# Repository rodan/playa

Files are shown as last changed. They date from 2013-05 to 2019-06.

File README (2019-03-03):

 This project has the following feature set:

   - a smallish and spartan music player that can work for weeks between charges
   - a 2Ah Li-poly cell and an integrated charger - 5V input
   - decoding of ogg vorbis, mp3 files
   - microSD (SDHC) is the storage medium. so fat32 and cards bigger than 4G.

  there are 2 components in this repository:
  avr        - contains the C source code for an Atmel-based microcontroller
  beaglebone - contains the C source code for beagle-bone (ARMv7)-based tools
  hardware   - open source hardware for the main board
				the schematic is based on VLSI's Simple DSP Evaluation Board [1]

  Library dependencies for the avr code:

   if using the master branch:
      none (this is a fully standalone version)

   if using the old 'arduino' branch:
      sdfatlib    http://code.google.com/p/sdfatlib/
      vs1063      https://github.com/rodan/vs1063
      IRremote    https://github.com/shirriff/Arduino-IRremote

  Usage:
   - an RC5 remote control provides the control (a Vishay TSOP IR receiver's output goes to PD2).
   - by default music files are played randomly. the following buttons are configured:
   
    VOL-        decrease volume
    VOL+        increase volume
    SUBTITLES   switch between 4 levels of spatial processing (for headphones)
    REWIND      switch to album mode
    CHANNEL-    switch to artist mode
    CHANNEL+    next track in either of the modes
    STOP        sends the player in low power shutdown mode. 
                you need to start it again to exit this.
    NUMBERS 0-9 select artist (which directory from the root of the filesystem to play)
    AV          disable artist selection

  Power consumption profile:
   - jumper/switch open - battery connected only to the charging circuit - < 3uA
   - normal file decoding - 30-40 mA
   - shutdown (after STOP ir command), IR sensor active - 800uA
   - after uC woken up by ir sensor trigger, waiting for a POWER ir sequence (for max 2 seconds) - 4.5mA (this mode has been disabled in the code)
   - if the stereo jack is unused or if the battery level goes below safe LiPo levels then the player enters shutdown mode.

  Known problems and limitations:
   - you should format the SDcard as Fat32 with largest available cluster size
   - no special chars must be used in the filesystem entries, only ascii alphanumeric chars
   - there is a hardcoded MAX_PATH that only allows about 4 parent dirs to any music file

  Tested with:
   - 16G Class 10 Adata card, with ogg files over the 4G barrier

  Author:            Petre Rodan <2b4eda@subdimension.ro>
  Available from:    https://github.com/rodan/playa
  Product pictures:  https://photos.app.goo.gl/nUQuD7HJvfVBpMeQ9
  License:           GNU GPLv3

[1]  http://www.vlsi.fi/en/support/evaluationboards/vs1053vs8053simpledspboard.html

 GNU GPLv3 license:
  
  This program is free software: you can redistribute it and/or modify
  it under the terms of the GNU General Public License as published by
  the Free Software Foundation, either version 3 of the License, or
  (at your option) any later version.
   
  This program is distributed in the hope that it will be useful,
  but WITHOUT ANY WARRANTY; without even the implied warranty of
  MERCHANTABILITY or FITNESS FOR A PARTICULAR PURPOSE.  See the
  GNU General Public License for more details.
   
  You should have received a copy of the GNU General Public License
  along with this program.  If not, see <http://www.gnu.org/licenses/>.

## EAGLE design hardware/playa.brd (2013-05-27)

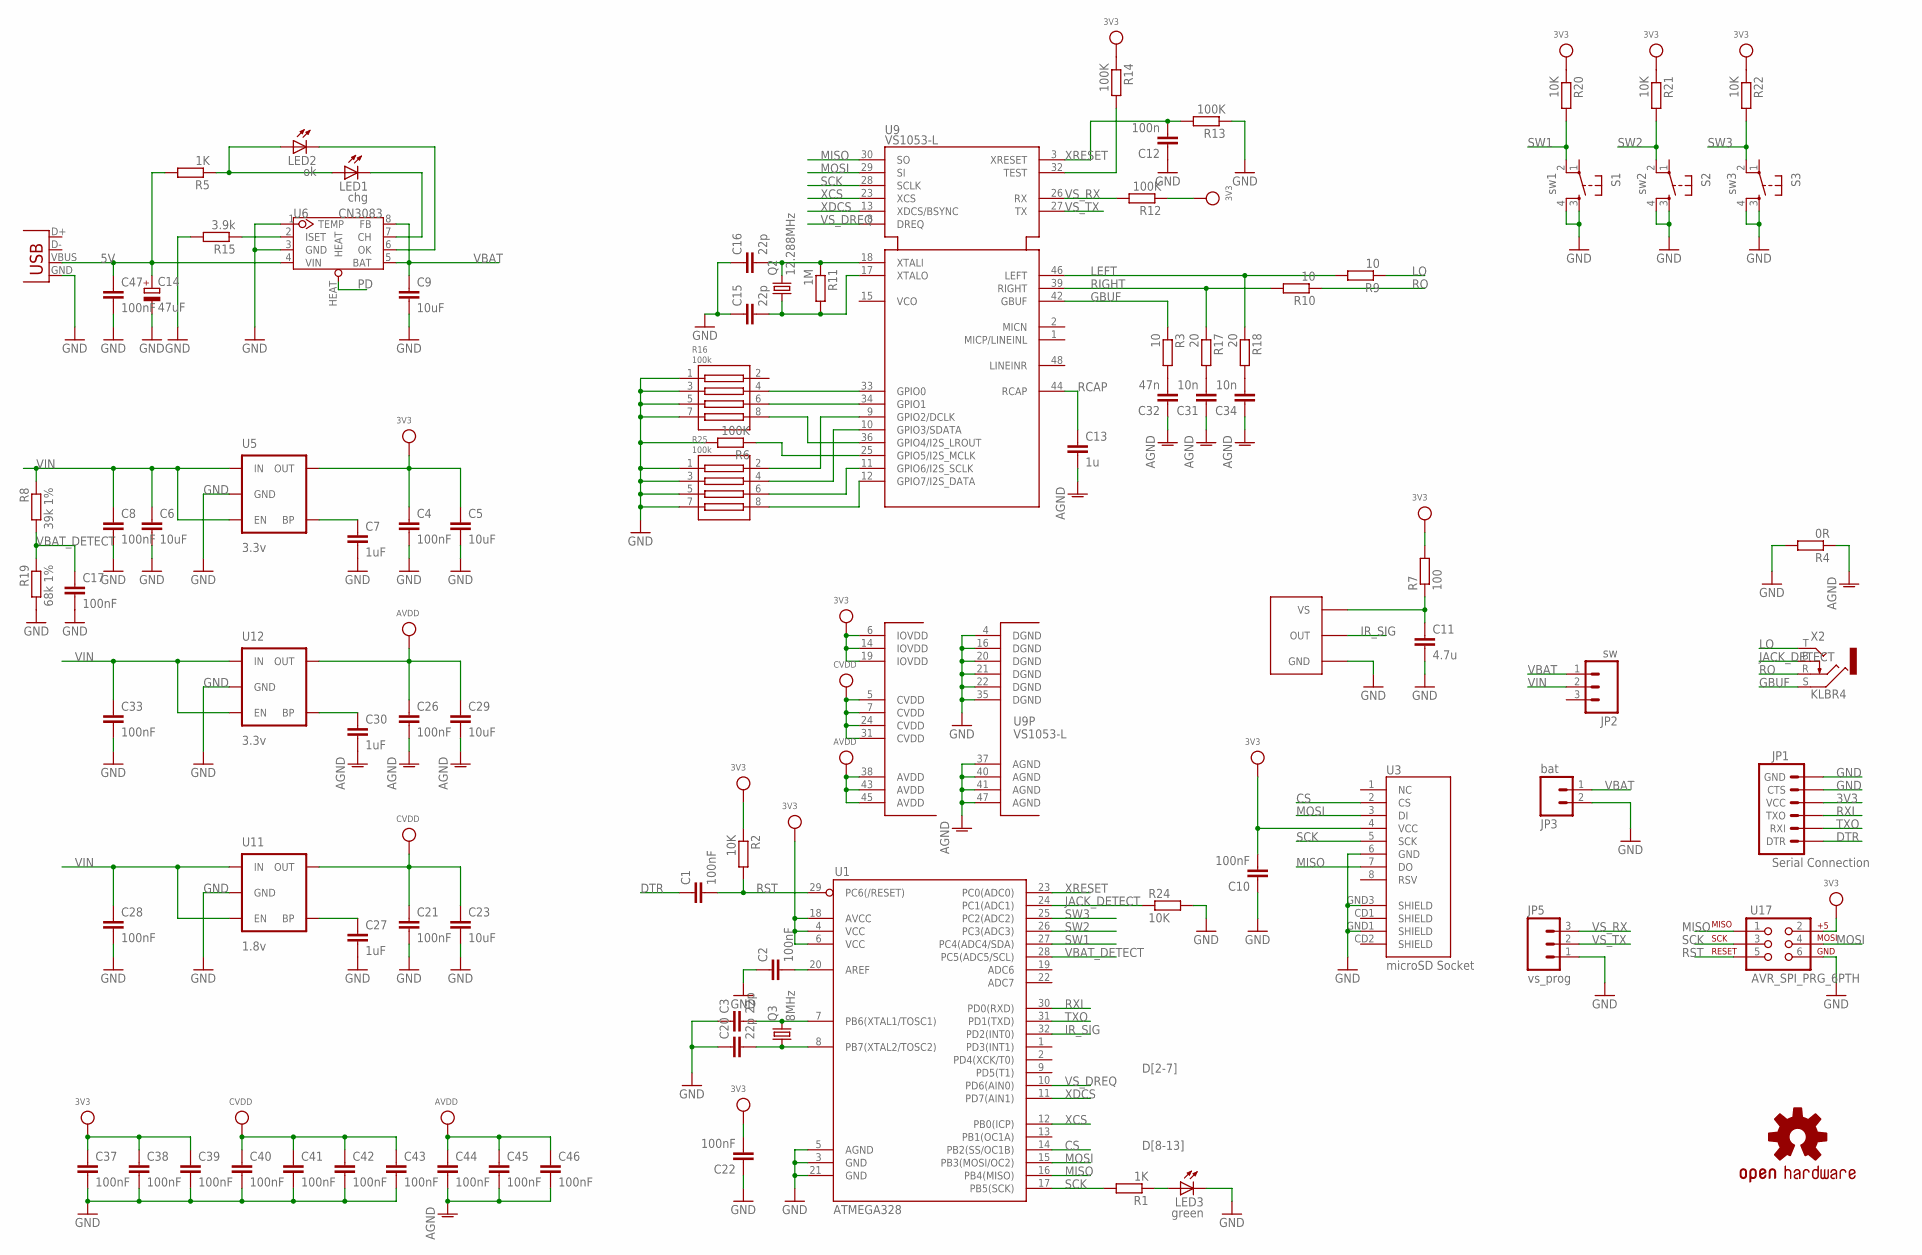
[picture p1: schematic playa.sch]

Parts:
C1, C2, C4, C8, C10, C17, C21, C22, C26, C28, C33, C37, C38, C39, C40, C41, C42, C43, C44, C45, C46, C47: 100nF; C0805
C3, C15, C16, C20: 22p; C0805
C5, C6, C9, C23, C29: 10uF; C1206
C7, C27, C30: 1uF; C0805
C11: 4.7u; C1206
C12: 100n; C0805
C13: 1u; C0805
C14: 47uF; CT7343
C31, C34: 10n; C0805
C32: 47n; C0805
JP1: Serial Connection; 1X06
JP2: sw; 1X03
JP3: bat; 1X02
JP5: vs_prog; 1X03
LED1: chg; CHIP-LED0805
LED2: ok; CHIP-LED0805
LED3: green; CHIP-LED0805
Q2: 12.288MHz; CRYSTAL_5X3.2
Q3: 8MHz; CRYSTAL_5X3.2
R1, R5: 1K; R0805W
R2, R20, R21, R22, R24: 10K; R0805W
R3, R9, R10: 10; R0805W
R4: 0R; R0805W
R6, R12, R13, R14: 100K; R0805W
R7: 100; R0805W
R8: 39k 1%; R0805W
R11: 1M; R0805W
R15: 3.9k; R0805W
R16, R25: 100k; RAS_ARR_1206
R17, R18: 20; R0805W
R19: 68k 1%; R0805W
S1: sw1; TACTILE_SWITCH_SMD
S2: sw2; TACTILE_SWITCH_SMD
S3: sw3; TACTILE_SWITCH_SMD
U1: ATMEGA328; TQFP32-08
U3: microSD Socket; MICRO-SD-SOCKET-PP
U5, U12: 3.3v; SOT23-5
U6: CN3083; SOP8-W/-HEAT
U9: VS1053-L; LQFP48
U11: 1.8v; SOT23-5
U17: AVR_SPI_PRG_6PTH; 2X3
U$3: TSOP312X
U$5: OSHW-LOGOM; OSHW-LOGO-M
X1: USBSMD; USB-MINIB
X2: KLBR4

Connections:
3V3: C4.1, C5.1, C10.2, C22.2, C37.1, C38.1, C39.1, JP1.4 (VCC), R2.1, R7.2, R12.1, R14.1, R20.1, R21.1, R22.1, U1.4 (VCC), U1.6 (VCC), U1.18 (AVCC), U3.4 (VCC), U5.5 (OUT), U9.6 (IOVDD), U9.14 (IOVDD), U9.19 (IOVDD), U17.2
5V: C14.+, C47.1, R5.2, U6.4 (VIN), X1.VBUS
AGND: C13.2, C26.2, C29.2, C30.2, C31.1, C32.1, C34.1, C44.2, C45.2, C46.2, R4.1, U9.37 (AGND), U9.40 (AGND), U9.41 (AGND), U9.47 (AGND)
AVDD: C26.1, C29.1, C44.1, C45.1, C46.1, U9.38 (AVDD), U9.43 (AVDD), U9.45 (AVDD), U12.5 (OUT)
CS: U1.14 (PB2(SS/OC1B)), U3.2 (CS)
CVDD: C21.1, C23.1, C40.1, C41.1, C42.1, C43.1, U9.5 (CVDD), U9.7 (CVDD), U9.24 (CVDD), U9.31 (CVDD), U11.5 (OUT)
DTR: C1.1, JP1.1 (DTR)
GBUF: R3.1, U9.42 (GBUF), X2.S
GND: C2.1, C3.1, C4.2, C5.2, C6.2, C7.2, C8.2, C9.2, C10.1, C11.2, C12.1, C14.-, C15.1, C16.1, C17.2, C20.1, C21.2, C22.1, C23.2, C27.2, C28.2, C33.2, C37.2, C38.2, C39.2, C40.2, C41.2, C42.2, C43.2, C47.2, JP1.5 (CTS), JP1.6 (GND), JP3.2, JP5.1, LED3.C, R4.2, R6.2, R13.1, R15.2, R16.1, R16.3, R16.5, R16.7, R19.2, R24.2, R25.1, R25.3, R25.5, R25.7, S1.3, S1.4, S2.3, S2.4, S3.3, S3.4, U1.3 (GND), U1.5 (AGND), U1.21 (GND), U3.6 (GND), U3.GND1 (SHIELD), U3.GND3 (SHIELD), U5.2 (GND), U6.1 (TEMP), U6.3 (GND), U9.4 (DGND), U9.16 (DGND), U9.20 (DGND), U9.21 (DGND), U9.22 (DGND), U9.35 (DGND), U11.2 (GND), U12.2 (GND), U17.6, U$3.1 (GND), X1.GND
IR_SIG: U1.32 (PD2(INT0)), U$3.3 (OUT)
JACK_DETECT: R24.1, U1.24 (PC1(ADC1)), X2.B
LEFT: R9.2, R18.1, U9.46 (LEFT)
LO: R9.1, X2.T
MISO: U1.16 (PB4(MISO)), U3.7 (DO), U9.30 (SO), U17.1
MOSI: U1.15 (PB3(MOSI/OC2)), U3.3 (DI), U9.29 (SI), U17.4
unnamed: C20.2, Q3.P$1 (1), U1.8 (PB7(XTAL2/TOSC2))
unnamed: C3.2, Q3.P$2 (2), U1.7 (PB6(XTAL1/TOSC1))
unnamed: C2.2, U1.20 (AREF)
unnamed: R16.4, U9.33 (GPIO0)
unnamed: C7.1, U5.4 (BP)
unnamed: R25.8, U9.12 (GPIO7/I2S_DATA)
unnamed: C27.1, U11.4 (BP)
unnamed: C32.2, R3.2
unnamed: R15.1, U6.2 (ISET)
unnamed: C31.2, R17.2
unnamed: C34.2, R18.2
unnamed: R16.6, U9.34 (GPIO1)
unnamed: LED3.A, R1.1
unnamed: LED1.A, LED2.A, R5.1
unnamed: LED1.C, U6.7 (CH)
unnamed: LED2.C, U6.6 (OK)
unnamed: R16.8, U9.36 (GPIO4/I2S_LROUT)
unnamed: C30.1, U12.4 (BP)
unnamed: R6.1, U9.25 (GPIO5/I2S_MCLK)
unnamed: R25.2, U9.9 (GPIO2/DCLK)
unnamed: R25.4, U9.10 (GPIO3/SDATA)
unnamed: R25.6, U9.11 (GPIO6/I2S_SCLK)
unnamed: C11.1, R7.1, U$3.2 (VS)
unnamed: R14.2, U9.32 (TEST)
PD: U6.HEAT
RCAP: C13.1, U9.44 (RCAP)
RIGHT: R10.2, R17.1, U9.39 (RIGHT)
RO: R10.1, X2.R
RST: C1.2, R2.2, U1.29 (PC6(/RESET)), U17.5
RXI: JP1.3 (TXO), U1.30 (PD0(RXD))
SCK: R1.2, U1.17 (PB5(SCK)), U3.5 (SCK), U9.28 (SCLK), U17.3
SW1: R20.2, S1.2, U1.27 (PC4(ADC4/SDA))
SW2: R21.2, S2.2, U1.26 (PC3(ADC3))
SW3: R22.2, S3.2, U1.25 (PC2(ADC2))
TXO: JP1.2 (RXI), U1.31 (PD1(TXD))
VBAT: C9.1, JP2.1, JP3.1, U6.5 (BAT), U6.8 (FB)
VBAT_DETECT: C17.1, R8.2, R19.1, U1.28 (PC5(ADC5/SCL))
VIN: C6.1, C8.1, C28.1, C33.1, JP2.2, R8.1, U5.1 (IN), U5.3 (EN), U11.1 (IN), U11.3 (EN), U12.1 (IN), U12.3 (EN)
VS_DREQ: U1.10 (PD6(AIN0)), U9.8 (DREQ)
VS_RX: JP5.3, R12.2, U9.26 (RX)
VS_TX: JP5.2, U9.27 (TX)
VS_XTALI: C16.2, Q2.P$2 (2), R11.1, U9.18 (XTALI)
VS_XTALO: C15.2, Q2.P$1 (1), R11.2, U9.17 (XTALO)
XCS: U1.12 (PB0(ICP)), U9.23 (XCS)
XDCS: U1.11 (PD7(AIN1)), U9.13 (XDCS/BSYNC)
XRESET: C12.2, R13.2, U1.23 (PC0(ADC0)), U9.3 (XRESET)

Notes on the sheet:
D[2-7]
D[8-13]

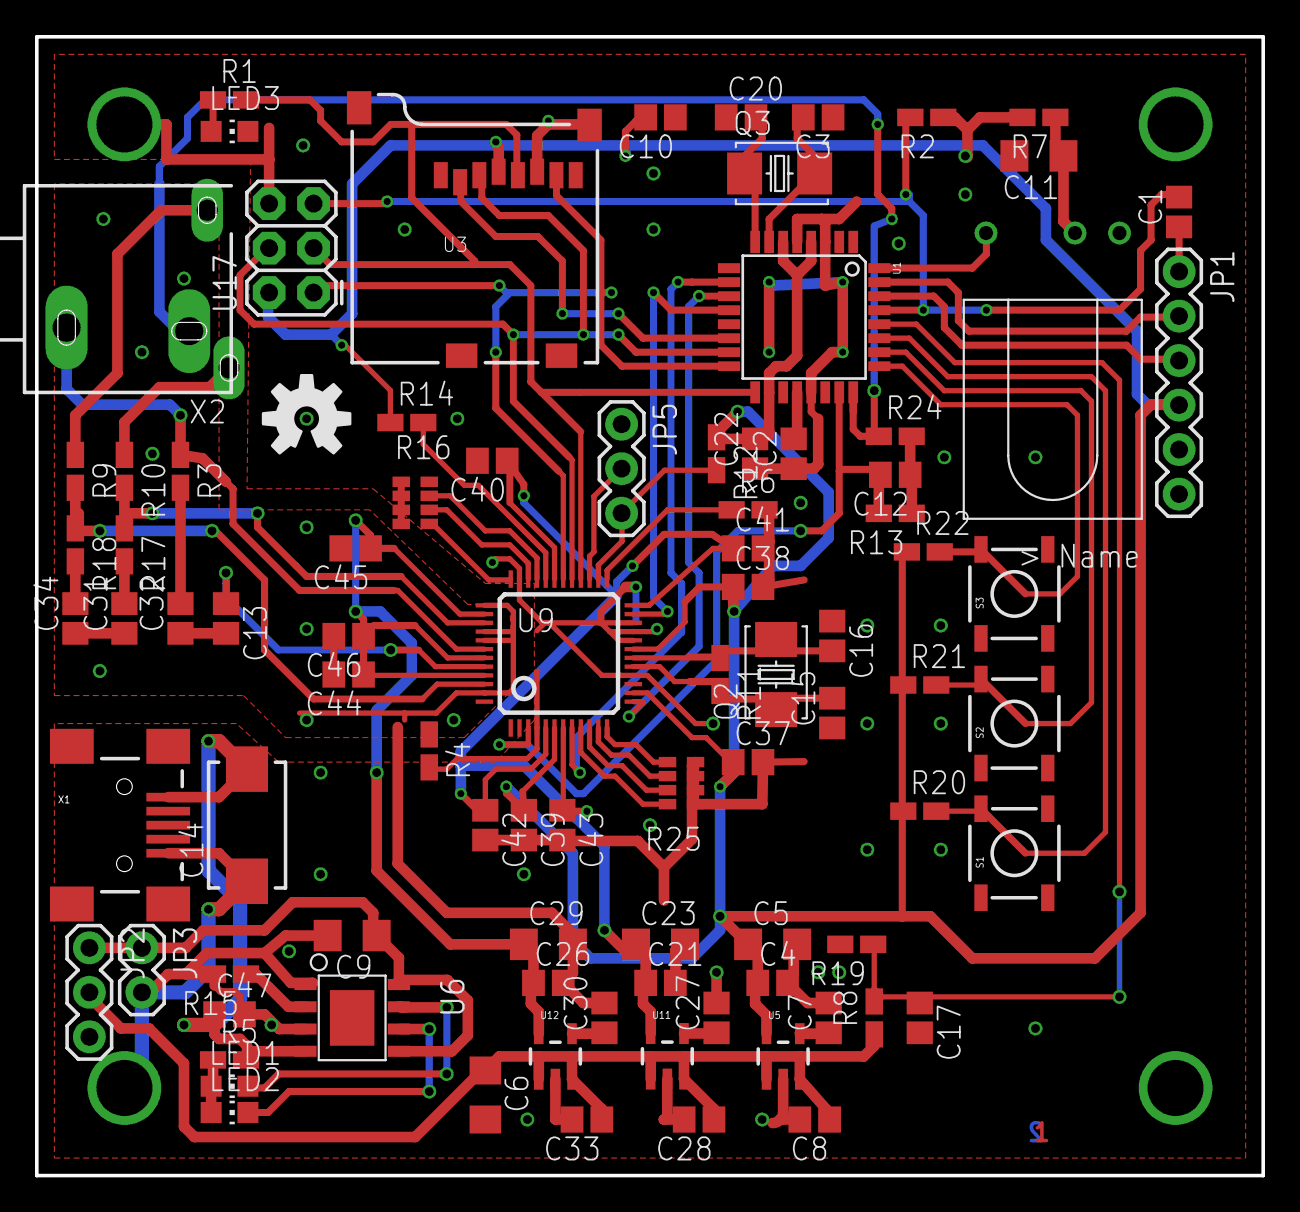
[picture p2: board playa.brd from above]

Board: 2 copper layers, 70.0 x 65.0 mm, 89 parts (0 on the bottom side), 60 nets.

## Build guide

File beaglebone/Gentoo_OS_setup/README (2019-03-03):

# nand mmc
drive_mmc='/dev/mmcblk1'
part_root="${drive_mmc}p1"
part_var="${drive_mmc}p2"

# sdcard root
part_sd_boot='/dev/mmcblk0p1'
part_sd_root='/dev/mmcblk0p2'

# prepare u-boot for internal flash-based booting

wget https://rcn-ee.com/repos/git/u-boot-patches/v2019.01/0001-am335x_evm-uEnv.txt-bootz-n-fixes.patch
wget ftp://ftp.denx.de/pub/u-boot/u-boot-2019.01.tar.bz2
tar -xjvf u-boot-2019.01.tar.bz2
cd u-boot-2019.01
patch -p1 < ../0001-am335x_evm-uEnv.txt-bootz-n-fixes.patch
patch -p1 < ../config.patch

make ARCH=arm CROSS_COMPILE=armv7a-hardfloat-linux-gnueabihf- am335x_boneblack_config
make ARCH=arm CROSS_COMPILE=armv7a-hardfloat-linux-gnueabihf-

# save MBR
dd if=${drive_mmc} of=mbr.bin bs=512 count=1

# fill pre-partition zone with zeroes
dd if=/dev/zero of=${drive_mmc} bs=4M count=1

# put back MBR
dd if=mbr.bin of=${drive_mmc} bs=512 count=1

# install the new bootloaders
dd if=MLO of=${drive_mmc} bs=512 seek=256 count=256 conv=notrunc
dd if=u-boot.img of=${drive_mmc} bs=512 seek=768 count=1024 conv=notrunc

parted --script ${drive_mmc} 'print' 2>&1 | grep -q 'unrecognised disk label' && {
  parted --script "${drive_mmc}" 'mklabel msdos'
  parted --script "${drive_mmc}" 'mkpart primary ext2 4M -512M'
  parted --script "${drive_mmc}" 'mkpart primary ext2 -512M -1'
  parted --script "${drive_mmc}" 'set 1 boot'
}
fdisk -l /dev/mmcblk1

Disk /dev/mmcblk1: 3.6 GiB, 3825205248 bytes, 7471104 sectors
Units: sectors of 1 * 512 = 512 bytes
Sector size (logical/physical): 512 bytes / 512 bytes
I/O size (minimum/optimal): 512 bytes / 512 bytes
Disklabel type: dos
Disk identifier: 0x7c96be87

Device         Boot   Start     End Sectors  Size Id Type
/dev/mmcblk1p1 *       8192 6471679 6463488  3.1G 83 Linux
/dev/mmcblk1p2      6471680 7469055  997376  487M 83 Linux

mkfs.ext2 -t ext2 -L root ${part_root}
mkfs.ext2 -t ext2 -L root ${part_var}

mkdir -p /mnt/mmc_root /mnt/mmc_var
mount "${part_root}" /mnt/mmc_root
mount "${part_var}" /mnt/mmc_var

# install boot loaders conforming to omap4+ partitioning layout
dd if=MLO of=${drive_mmc} count=1 seek=1 conv=notrunc bs=128k
dd if=u-boot.img of=${drive_mmc} count=2 seek=1 conv=notrunc bs=384k

mkdir -p /mnt/sd_boot /mnt/sd_root
mount "${part_sd_boot}" /mnt/sd_boot
mount "${part_sd_root}" /mnt/sd_root

rsync --specials --delete --recursive --times --links --hard-links --perms --owner --group --numeric-ids --devices --sparse /mnt/sd_root/ /mnt/mmc_root/

rsync --specials --delete --recursive --times --links --hard-links --perms --owner --group --numeric-ids --devices --sparse /mnt/sd_boot/ /mnt/mmc_root/boot/

setenv bootpart 1:1
setenv boot_targets mmc1
setenv init_console setenv console ttyS0,115200n8;
setenv loadfdt load \${devtype} \${bootpart} \${fdtaddr} \${bootdir}/dtbs/\${fdtfile}
saveenv

Resources:

https://wiki.beyondlogic.org/index.php?title=BeagleBoneBlack_Upgrading_uBoot
https://github.com/beagleboard/bb.org-overlays/blob/master/src/arm/univ-bbb-EVA-00A0.dts
https://elinux.org/BeagleBone_Black_Enable_SPIDEV
https://elinux.org/Beagleboard:U-boot_partitioning_layout_2.0
https://github.com/derekmolloy/exploringBB

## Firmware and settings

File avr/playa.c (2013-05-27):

#include <stdio.h>
#include <stdlib.h>
#include <string.h>
#include <avr/io.h>
#include <avr/interrupt.h>
#include <avr/pgmspace.h>
#include <avr/wdt.h>
#include <avr/sleep.h>
#include <avr/power.h>

#include "playa.h"
#include "drivers/timer.h"
#include "drivers/adc.h"
#include "drivers/uart.h"
#include "drivers/spi.h"
#include "drivers/diskio.h"
#include "drivers/vs1063.h"
#include "drivers/ir_remote.h"
#include "fatfs/ff.h"

// vs1063
uint8_t cbuff[CARD_BUFF_SZ];
uint8_t volume = 40;            // as negative attenuation. can go from 0x00 lound - 0xfe silent
                     // 0xff is a special case (analog powerdown mode)
uint8_t ear_speaker_lvl = 0;

// infrared remote
uint32_t result_last = 11111;
uint16_t ir_delay = 400;        // delay between repeated button presses
uint32_t ir_delay_prev = 0;
uint8_t ir_cmd;
uint8_t play_mode = PLAY_RANDOM;
uint8_t mute = 0;
uint16_t in_number = 0;

// fatfs
DSTATUS dstatus;                // disc status set by disk_initialize()
FATFS fs;                       // mounted entity
DIR dir;
FIL file;
uint8_t path_level;
char file_path[MAX_PATH];
char album_path[MAX_PATH];

// misc
uint16_t seed;

// sleep states
volatile uint8_t just_woken;
volatile uint8_t sleeping = 0;
uint32_t wake_up_time = 0;      // systemtime when the uC was woken up
uint16_t wake_up_delay = 4000;  // the delay until the uC is powered down again

//#ifdef DEBUG
char str_temp[64];
//#endif

int main(void)
{
    setup();

    for (;;) {
        wdt_reset();
        ui_ir_decode();
        if (play_mode != STOP) {
            env_check();
        } else {
            sleep_mgmt();
        }
        ui();
    }
}

void setup(void)
{
    timer_init();
    sei();
    delay(100); // debounce/allow caps to charge

//#ifdef DEBUG
    uart_init(UART_BAUD_SELECT(9600, F_CPU));
    uart_puts_P("?");
//#else
//    power_usart0_disable();
//#endif

    wdt_enable(WDTO_8S);        // Enable watchdog: max 8 seconds
    cli();
    power_twi_disable();
    power_timer1_disable();
    sei();
    ir_init();
    spi_init();
    vs_setup();
    vs_setup_local();

    just_woken = 0;

    if (f_mount(0, &fs) == FR_OK) {
        dstatus = disk_initialize(0);
        if (dstatus & (STA_NOINIT | STA_NODISK | STA_PROTECT)) {
            play_mode = STOP;
        }
    } else {
        play_mode = STOP;
    }

}

void vs_setup_local(void)
{
    //initialize chip 
    vs_deselect_control();
    vs_deselect_data();
    vs_set_volume(0xff, 0xff);
    //AVDD is at least 3.3v, so select 1.65v reference to increase 
    //the analog output swing
    vs_write_register(SCI_STATUS, SS_REFERENCE_SEL);
    // Declick: Slow sample rate for slow analog part startup
    vs_write_register_hl(SCI_AUDATA, 0, 10);    // 10 Hz
    // Switch on the analog parts
    vs_write_register_hl(SCI_AUDATA, 31, 64);   // 8kHz
    vs_soft_reset();
    vs_set_volume(volume, volume);
}

uint8_t ui_ir_decode(void)
{
    uint32_t now;
    int8_t ir_number = -1;

    now = millis();

    if (ir_decode(&results)) {

        if ((results.decode_type == RC5) && (results.value >= 2048))
            results.value -= 2048;

        // if we woke up from sleep, only allow a power-up command
        if ((just_woken) && (results.value != 12)) {
            ir_resume();
            return 1;
        }

        if ((just_woken == 0) && (results.value == result_last)
            && (now - ir_delay_prev < ir_delay)) {
            ir_resume();
            return 1;
        }
#ifdef DEBUG
        sprintf(str_temp, "%ld\r\n", results.value);
        uart_puts(str_temp);
#endif

        switch (results.value) {
            // RC5 codes
        case 1:                // 1
            ir_number = 1;
            break;
        case 2:                // 2
            ir_number = 2;
            break;
        case 3:                // 3
            ir_number = 3;
            break;
        case 4:                // 4
            ir_number = 4;
            break;
        case 5:                // 5
            ir_number = 5;
            break;
        case 6:                // 6
            ir_number = 6;
            break;
        case 7:                // 7
            ir_number = 7;
            break;
        case 8:                // 8
            ir_number = 8;
            break;
        case 9:                // 9
            ir_number = 9;
            break;
        case 0:                // 0
            ir_number = 0;
            break;
//        case 10: // 10
//            ir_number = 10;
//            break;
        case 12:               // power
            // wake up from pwr_down
            if (just_woken == 1) {
                just_woken = 0;
                wake_up_time = 0;
                play_mode = PLAY_RANDOM;
            }
            break;
        case 56:               // AV
            in_number = 0;
            break;
/*        case 36: // red
          break;
        case 35: // green
          break;
        case 14: // yellow
          break;
        case 50: // zoom
            break;
*/
        case 39: // sub
            ear_speaker_lvl++;
            vs_ear_speaker(ear_speaker_lvl);
            //sprintf(str_temp, "ear 0x%04x\r\n", vs_read_wramaddr(earSpeakerLevel));
            //uart_puts(str_temp);
            break;
/*
        case 44: // slow
            break;
        case 60: // repeat
            break;
        case 15: // disp
            break;
        case 38: // sleep
            break;
        case 32: // up
            break;
        case 33: // down
            break;
        case 16: // right
            break;
        case 17: // left
            break;
        case 59: // ok
            break;
        case 34: // back
            break;
        case 19: // exit
            break;
        case 18: // menu
            break;
*/
        case 13:
        case 0x290:            // mute
            mute = 1;
            vs_set_volume(0xfe, 0xfe);
            break;
        case 16:
        case 0x490:            // vol+
            mute = 0;
            if (volume > 3) {
                volume -= 4;    // decrease attenuation by 2dB
                vs_set_volume(volume, volume);
            }
            break;
        case 17:
        case 0xc90:            // vol-
            mute = 0;
            if (volume < 251) {
                volume += 4;    // increase attenuation by 2dB
                vs_set_volume(volume, volume);
            }
            break;
        case 28:
        case 0x90:             // ch+
            ir_cmd = CMD_EXIT;
            break;
        case 29:
        case 0x890:            // ch-
            in_number++;
            ir_cmd = CMD_EXIT;
            break;
/*
        case 36:               // record
            //sprintf(str_temp, "SCI_MODE 0x%04x\r\n", vs_read_register(SCI_MODE));
            //uart_puts(str_temp);
            break;
*/
        case 54:
        case 0xa90:            // stop
            if (play_mode != STOP) {    // do this loop only once
                //vs_write_register(SCI_MODE, SM_CANCEL);
                // to minimize the power-off transient
                vs_set_volume(0xfe, 0xfe);
                delay(10);
                play_mode = STOP;
                ir_cmd = CMD_EXIT;
            }
            break;
//        case 14:               // play
//            break;
//        case 31:               // pause
//            break;
        case 35:
        case 0xa50:            // rew, AV/TV
            if (in_number != 0) {
                in_number = 0;
            } else {
                if (play_mode == PLAY_RANDOM)
                    play_mode = SWITCH_TO_ALBUM;
                if (play_mode == PLAY_ALBUM)
                    play_mode = PLAY_RANDOM;
            }
            ir_cmd = CMD_EXIT;
            break;
//        case : // fwd
//            break;
        default:
            break;
        }                       // switch

        // vol+ and vol- should not care about ir_delay
        if ((results.value != 11111) && (results.value != 16)
            && (results.value != 17) && (results.value != 0xc90) &&
            (results.value != 0x490)) {
            result_last = results.value;
            ir_delay_prev = millis();
        }
        // get a number from the ir remote
        if (ir_number > -1) {
            in_number = in_number * 10 + ir_number;
        }
        ir_resume();            // Receive the next keypress
    }
    return 0;
}

void env_check(void)
{
    uint16_t vbat, jack_detect;
    uint8_t i;

    // jack_detect is zero if a stereo jack is physically plugged in. 
    // otherwise the common voltage for the earphones (aka GBUF) is read (1.65v)
    //
    // vbat's value is (1024/Vref)*Vbattery*R2/(R1+R2), where
    //    Vref     - ADC voltage reference - 3.3v
    //    Vbattery - actual battery voltage (should be between 3 and 4.2v)
    //    R2       - 68Kohm
    //    R1       - 39Kohm
    // we try to limit current consumption when the Lipo cell reaches about 3.6v.
    // Note:
    //   this formula is usable only when Vref is actually 3.3v. 
    //   in case the cell voltage is below ~3.5v, vbat is not read correctly
    //   and the only thing protecting the cell is the internal cutoff

    vbat = analogRead(PIN_VBAT_DETECT);
    jack_detect = analogRead(PIN_JACK_DETECT);

    // attempt to gather some entropy from the outside
    // sometimes PIN_RANDOM gives the same values, so keep and increment seed between runs
    seed += millis();
    for (i = 0; i < vbat / 10; i++) {
        seed += analogRead(PIN_RANDOM);
    }
    srandom(seed);
    for (i = 0; i < vbat / 10; i++) {
        random();               // apparently randomSeed does not provide proper randomness
    }

    if ((vbat < 712) || (jack_detect > 0)) {
        // shut down vs1063 to protect the Lipo cell
        play_mode = STOP;
    }
}

void ui(void)
{
    switch (play_mode) {
    case STOP:
        break;
    case PLAY_RANDOM:
        path_level = 0;
        f_opendir(&dir, "/");
        memset(file_path, 0, MAX_PATH);
        file_find_random();
        break;
    case PLAY_ALBUM:
        file_find_next();
        break;
    case SWITCH_TO_ALBUM:
        play_mode = PLAY_ALBUM;
        get_album_path();
        f_opendir(&dir, album_path);
        f_readdir(&dir, NULL);  // rewind dir
        file_find_next();
        break;
    }
}

void get_album_path(void)
{
    uint8_t i;
    uint8_t l = 0;
    for (i = 0; i < MAX_PATH; i++) {
        if (file_path[i] == '/')
            l = i;
    }
    strncpy(album_path, file_path, l);
    album_path[l] = 0;          // album_path[] and file_pathp[] have the same size
    // so there is no buffer overflow here
}

uint8_t play_file(void)
{
    uint16_t i, tx_len;
    uint8_t count = 0;
    uint8_t checked = 0;
    uint16_t codec = 0x0eaa;    // something unused
    int16_t replaygain_offset = 0;
    uint8_t replaygain_volume;
    FRESULT res;
    UINT r;

//#define DEBUG
    uart_puts(file_path);
    uart_puts_P("\r\n");
//#endif

    vs_soft_reset();

    if (f_open(&file, file_path, FA_OPEN_EXISTING | FA_READ)) {
        return 1;
    }

    for (;;) {
        res = f_read(&file, cbuff, CARD_BUFF_SZ, &r);
        if (res || r == 0) {
            vs_deselect_data();
            //sprintf(str_temp, "E f_read 0x%x\r\n", res);
            //uart_puts(str_temp);
            vs_end_play();
            delay(100);
            break;              // file open err or EOF
        }
        if (!checked)
            count++;
        if (!checked && count > 100) {
            vs_deselect_data();
            // sometimes the decoder never gets busy while reading non-music data
            // so we exit here
            if (vs_read_register(SCI_HDAT1) == 0) {
                uart_puts_P("HDAT1 err\r\n");
                f_close(&file);
                vs_cancel_play();
                delay(100);
                return 1;
            }
        }
        vs_select_data();
        i = 0;
        while (i < r) {
            while (!(VS_DREQ_PIN & VS_DREQ)) {
                // the VS chip is busy, so do something else
                vs_deselect_data();     // Release the SDI bus
                wdt_reset();
                ui_ir_decode();
                //if ((ir_cmd == CMD_EXIT) || (codec == 0)) {
                if (ir_cmd == CMD_EXIT) {
                    ir_cmd = CMD_NULL;
                    f_close(&file);
                    vs_cancel_play();
                    delay(100);
                    return 0;
                }
                if (!checked && count > 1) {
                    vs_deselect_data();
                    // do a one-time check of the codec status
                    codec = vs_read_register(SCI_HDAT1);
                    if (codec == 0x4f67) {
                        // if ogg, read the replaygain offset
                        replaygain_offset = vs_read_wramaddr(ogg_gain_offset);
                        if (replaygain_offset < 10 && replaygain_offset > -30) {
                            replaygain_volume =
                                volume - (replaygain_offset + 12);
                            if (!mute) {
                                vs_set_volume(replaygain_volume,
                                              replaygain_volume);
                            }
                            //uart_putsln(volume);
                            //uart_putsln(replaygain_offset);
                            //uart_putsln(replaygain_volume);
                        }
                    }
                    checked = 1;
                }
                vs_select_data();       // Pull XDCS low
            }                   // the mint rubbing function

            if (VS_BUFF_SZ > r) {
                tx_len = r;
            } else if (i + VS_BUFF_SZ > r) {
                tx_len = r % VS_BUFF_SZ;
            } else {
                tx_len = VS_BUFF_SZ;
            }

            // send up to 32bytes after a VS_DREQ check
            vs_wait();
            spi_transmit_sync(cbuff, i, tx_len);
            i += tx_len;
        }
        vs_wait();
        vs_deselect_data();
    }

    vs_write_register(SCI_MODE, SM_CANCEL);
    f_close(&file);
    return 0;
}

uint8_t file_find_next(void)
{
    FILINFO fno;

    if (f_readdir(&dir, &fno) == FR_OK) {
        if (fno.fname[0] != 0) {
            snprintf(file_path, MAX_PATH, "%s/%s", album_path, fno.fname);
        } else {
            // the album has ended
            play_mode = PLAY_RANDOM;
            return 0;
        }
    } else {
        return 1;
    }

    if (!(fno.fattrib & AM_DIR)) {
        play_file();
        return 0;
    } else {
        return 1;
    }

    return 0;
}

uint8_t file_find_random(void)
{
    FILINFO fno;

    uint16_t i = 0, items = 0, rnd;

    // how many items in the current dir?
    while (f_readdir(&dir, &fno) == FR_OK) {
        if (fno.fname[0] == 0) {
            break;
        }
        items++;
    }

    // rewind dir
    f_readdir(&dir, NULL);

    if (items == 0)
        return 1;

    if (path_level == 0) {
        if (in_number == 0) {
            // pick one at random, then either play it if it's a file
            // or cd into it and repeat until a file is found
            rnd = (random() % items) + 1;
        } else {
            rnd = (in_number % items) + 1;
        }
    } else {
        rnd = (random() % items) + 1;
    }

    for (i = 1; i <= rnd; i++) {
        f_readdir(&dir, &fno);
#ifdef DEBUG
        uart_puts(fno.fname);
        uart_puts_P("\r\n");
#endif
    }

    strncat(file_path, "/", 2);
    strncat(file_path, fno.fname, 14);

#ifdef DEBUG
    sprintf(str_temp, "%d path_lvl, %d items\r\n", path_level, items);
    uart_puts(str_temp);
    sprintf(str_temp, "%d seed, %d rnd, %d in_num\r\n", seed, rnd, in_number);
    uart_puts(str_temp);
    sprintf(str_temp, "%s path\r\n\r\n", file_path);
    uart_puts(str_temp);
#endif

    if (fno.fattrib & AM_DIR) {
        path_level++;
        if (f_opendir(&dir, file_path) == FR_OK) {
            if (path_level < 5) {
                file_find_random();
            } else {
                return 1;
            }
        } else {
            return 1;
        }
    } else {
        play_file();
    }

    return 0;
}

void sleep_mgmt(void)
{
    if (just_woken == 0) {
        //uart_puts_P("tmout\r\n");
        pwr_down();
    } else if (just_woken == 1) {
        if (wake_up_time == 0) {
            wake_up_time = millis();
        } else if (millis() - wake_up_time > wake_up_delay) {
            //sprintf(str_temp, "%ld %ld\r\n", millis(), wake_up_time);
            //uart_puts(str_temp);
            // if an IR signal woke up the uC from sleep, but that signal was not 
            // a power sequence then go back to sleep.
            pwr_down();
        }
    }
}

// used when STOP command is issued
void pwr_down(void)
{

    // recovery from low power land is not really functional
    // so it gets commented out

    wake_up_time = 0;
    vs_assert_xreset();
    wdt_disable();
    sleeping = 1;

    //cli();
    // wake up on remote control input (external INT0 interrupt)
    //EICRA = 0;                  //Interrupt on low level
    //EIMSK = (1 << INT0);        // enable INT0 interrupt
    //sei();

    spi_disable();
    power_all_disable();

    // proper sleep_enable sequence. see /usr/avr/include/avr/sleep.h
    set_sleep_mode(SLEEP_MODE_PWR_DOWN);
    for (;;) {
        cli();
        sleep_enable();
        sei();
        sleep_cpu();
    }

    /*
    sleep_disable();
    sei();

    wdt_enable(WDTO_8S);
    cli();
    EIMSK = 0;                  // disable INT interrupt
    sei();

    spi_init();
    vs_setup();

    // initialize chip
    vs_deselect_control();
    vs_deselect_data();
    vs_deassert_xreset();
    delay(500);
    vs_write_register(SCI_CLOCKF, 0x8800);
    vs_write_register(SCI_STATUS, SS_REFERENCE_SEL);
    vs_write_register_hl(SCI_AUDATA, 31, 64);   // 8kHz
    vs_set_volume(volume, volume);
    vs_soft_reset();

    just_woken = 1;
    sleeping = 0;
    */

}

/*
ISR(INT0_vect)
{
    if (sleeping == 1) {
        just_woken = 1;
    }
}
*/

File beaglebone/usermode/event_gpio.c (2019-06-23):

/*
Copyright (c) 2013 Adafruit

Original RPi.GPIO Author Ben Croston
Modified for BBIO Author Justin Cooper

This file incorporates work covered by the following copyright and 
permission notice, all modified code adopts the original license:

Copyright (c) 2013 Ben Croston

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
THE SOFTWARE IS PROVIDED "AS IS", WITHOUT WARRANTY OF ANY KIND, EXPRESS OR
IMPLIED, INCLUDING BUT NOT LIMITED TO THE WARRANTIES OF MERCHANTABILITY,
FITNESS FOR A PARTICULAR PURPOSE AND NONINFRINGEMENT. IN NO EVENT SHALL THE
AUTHORS OR COPYRIGHT HOLDERS BE LIABLE FOR ANY CLAIM, DAMAGES OR OTHER
LIABILITY, WHETHER IN AN ACTION OF CONTRACT, TORT OR OTHERWISE, ARISING FROM,
OUT OF OR IN CONNECTION WITH THE SOFTWARE OR THE USE OR OTHER DEALINGS IN THE
SOFTWARE.
*/

#include <errno.h>
#include <fcntl.h>
#include <pthread.h>
#include <stdio.h>
#include <stdlib.h>
#include <string.h>
#include <sys/epoll.h>
#include <syslog.h>
#include <unistd.h>

#include "event_gpio.h"
#include "common.h"

#define GPIO_NOT_EXPORTED 0
#define GPIO_EXPORTED 1
#define GPIO_ALREADY_EXPORTED 2

const char *stredge[4] = {"none", "rising", "falling", "both"};

// file descriptors
struct fdx
{
    int fd;
    unsigned int gpio;
    int initial;
    unsigned int is_evented;
    struct fdx *next;
};
struct fdx *fd_list = NULL;

// event callbacks
struct callback
{
    unsigned int gpio;
    void (*func)(unsigned int gpio);
    struct callback *next;
};
struct callback *callbacks = NULL;

pthread_t threads;
int exported_gpios[120] = { GPIO_NOT_EXPORTED };
int event_occurred[120] = { 0 };
int thread_running = 0;
int epfd = -1;

BBIO_err gpio_export(unsigned int gpio)
{
    int fd = 0, len = 0, ret = BBIO_GEN;
    char str_gpio[10];

    // already exported by us?
    if (exported_gpios[gpio] != GPIO_NOT_EXPORTED) {
        syslog(LOG_DEBUG, "Adafruit_BBIO: gpio_export(): %u already exported before", gpio);
        ret = BBIO_OK;
        goto exit;
    }

    // Is GPIO an LED?
    if ( ((gpio >= USR_LED_GPIO_MIN) && (gpio <=  USR_LED_GPIO_MAX)) 
         ||
         ( beaglebone_blue() 
           &&
           ( 
             (gpio == USR_LED_RED)
             || (gpio == USR_LED_GREEN)
             || (gpio == BAT25)
             || (gpio == BAT50)
             || (gpio == BAT75)
             || (gpio == BAT100)
             || (gpio == WIFI)
           ) 
         )
       )
    {
        syslog(LOG_WARNING, "Adafruit_BBIO: gpio_export: %u not applicable to built-in LEDs", gpio);
        return BBIO_OK; // export is not applicable to the USR LED pins
    }
        
    // already exported by someone else?
    char gpio_path[64];
    snprintf(gpio_path, sizeof(gpio_path), "/sys/class/gpio/gpio%d", gpio);

    if (access(gpio_path, R_OK|W_OK|X_OK) != -1) {
        exported_gpios[gpio] = GPIO_ALREADY_EXPORTED;
        syslog(LOG_DEBUG, "Adafruit_BBIO: gpio_export(): %u already exported externally", gpio);
        ret =  BBIO_OK;
        goto exit;
    }

    const char gpio_export[] = "/sys/class/gpio/export";

    if ((fd = open(gpio_export, O_WRONLY)) < 0) {
        syslog(LOG_ERR, "Adafruit_BBIO: gpio_export(): %u couldn't open \"%s\": %i-%s",
               gpio, gpio_export, errno, strerror(errno));
        ret =  BBIO_SYSFS;
        goto exit;
    }

    len = snprintf(str_gpio, sizeof(str_gpio), "%d", gpio);
    if(write(fd, str_gpio, len) < 0) {
        syslog(LOG_ERR, "Adafruit_BBIO: gpio_export: %u couldn't write \"%s\": %i-%s",
               gpio, gpio_export, errno, strerror(errno));
        ret =  BBIO_SYSFS;
        goto exit;
    }

    // add to list
    exported_gpios[gpio] = GPIO_EXPORTED;

    syslog(LOG_DEBUG, "Adafruit_BBIO: gpio_export(): %u OK", gpio);
    ret = BBIO_OK;

    exit:
    if(fd && (ret = close(fd))) {
        syslog(LOG_ERR, "Adafruit_BBIO: gpio_export(): %u couldn't close \"%s\": %i-%s",
               gpio, gpio_export, errno, strerror(errno));
        ret =  BBIO_SYSFS;
    }
    usleep(200000);      // Hack to wait for newly exported pins to get correct ownership
    return ret;
}
// Closes fd corresponding to specified GPIO pin and removes it from fdx list
void close_value_fd(unsigned int gpio)
{
    struct fdx *f = fd_list;
    struct fdx *temp;
    struct fdx *prev = NULL;

    while (f != NULL)
    {
        if (f->gpio == gpio)
        {
            close(f->fd);
            syslog(LOG_DEBUG, "Adafruit_BBIO: close_value_fd(): closed file descriptor %d", f->fd);
            if (prev == NULL)
                fd_list = f->next;
            else
                prev->next = f->next;
            syslog(LOG_DEBUG, "Adafruit_BBIO: close_value_fd(): removing file descriptor %d for pin %u from opened descriptors list",f->fd, f->gpio);
            temp = f;
            f = f->next;
            free(temp);
        } else {
            prev = f;
            f = f->next;
        }
    }
}
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

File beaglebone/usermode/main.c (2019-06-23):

#include <stdio.h>
#include <stdlib.h>
#include <ctype.h>
#include <inttypes.h>
#include <getopt.h>
#include <unistd.h>
#include <sys/stat.h>
#include <fcntl.h>
#include <linux/gpio.h>
#include <termios.h>
#include <string.h>
#include <poll.h>

#include "config.h"
#include "spi.h"
#include "vs1063.h"

#define POLL_TIMEOUT 100        // ms
#define MAX_BUF 64

uint8_t volume = 40;            // as negative attenuation. can go from 0x00 lound - 0xfe silent
                     // 0xff is a special case (analog powerdown mode)

//#define UI_NCURSES
//#define USE_POLL
#define USE_EPOLL

/*
static void pabort(const char *s)
{
    perror(s);
    abort();
}
*/

static void print_usage(const char *prog)
{
    printf("Usage: %s -i music_file [-d device] [h]\n", prog);
    puts("  -d --device       device to use\n"
         "  -i --input-file   music file to play\n" "  -h --help         show usage\n");
    exit(1);
}

void print_vs_registers()
{
    printf("SCI_MODE         0x%x\n", vs_read_register(SCI_MODE, WAIT_FOR_DREQ));
    printf("SCI_STATUS       0x%x\n", vs_read_register(SCI_STATUS, WAIT_FOR_DREQ));
    printf("SCI_CLOCKF       0x%x\n", vs_read_register(SCI_CLOCKF, WAIT_FOR_DREQ));
    printf("SCI_DECODE_TIME  0x%x\n", vs_read_register(SCI_DECODE_TIME, WAIT_FOR_DREQ));
    printf("SCI_AUDATA       0x%x\n", vs_read_register(SCI_AUDATA, WAIT_FOR_DREQ));
    printf("SCI_HDAT0        0x%x\n", vs_read_register(SCI_HDAT0, WAIT_FOR_DREQ));
    printf("SCI_HDAT1        0x%x\n", vs_read_register(SCI_HDAT1, WAIT_FOR_DREQ));
    printf("SCI_VOL          0x%x\n", vs_read_register(SCI_VOL, WAIT_FOR_DREQ));

    printf("DREQ state       0x%x\n", vs_get_dreq());
}

static struct termios oldt;

void restore_terminal_settings(void)
{
    tcsetattr(0, TCSANOW, &oldt);       // Apply saved settings
}

void disable_waiting_for_enter(void)
{
    struct termios newt;

    // Make terminal read 1 char at a time
    tcgetattr(0, &oldt);        // Save terminal settings
    newt = oldt;                // Init new settings
    newt.c_lflag &= ~(ICANON | ECHO);   // Change settings
    tcsetattr(0, TCSANOW, &newt);       // Apply settings
    atexit(restore_terminal_settings);  // Make sure settings will be restored when program ends
}

int main(int argc, char *argv[])
{
    char *input_file = NULL;
    int ret = 0;

    int timeout;
    struct pollfd fdset[1];
    int nfds = 1;
    char buf[MAX_BUF];
    char ui_in;

    while (1) {
        static const struct option lopts[] = {
            {"device", 1, 0, 'd'},
            {"input-file", 1, 0, 'i'},
            {"help", 0, 0, 'h'},
            {NULL, 0, 0, 0},
        };
        int c;

        c = getopt_long(argc, argv, "d:i:h", lopts, NULL);

        if (c == -1)
            break;

        switch (c) {
        case 'd':
            //device = optarg;
            break;
        case 'i':
            input_file = optarg;
            break;
        default:
            print_usage(argv[0]);
            break;
        }
    }

    if (input_file == NULL) {
        print_usage(argv[0]);
    }
    // stdin irq triggers before /n
    disable_waiting_for_enter();

    ret = vs_init();
    if (ret) {
        printf(" vs_setup() error 0x%x\n", ret);
        exit(1);
    }
    //initialize chip 
    //vs_set_volume(0xff, 0xff);

    // Declick: Slow sample rate for slow analog part startup
    //vs_write_register_hl(SCI_AUDATA, 0, 10);        // 10Hz
    // Switch on the analog parts
    //vs_write_register_hl(SCI_AUDATA, 0xac, 0x45);   // 44100Hz, stereo
    //vs_soft_reset();
    //vs_set_volume(volume, volume);

    //AVDD is at least 3.3v, so select 1.65v reference to increase 
    //the analog output swing
    //vs_write_register(SCI_STATUS, SS_REFERENCE_SEL);

    //print_vs_registers();

    //usleep(100000);             // allow caps to charge 
    //play_file(input_file);

    timeout = POLL_TIMEOUT;

    while (1) {
        buf[0] = 0;
        memset((void *)fdset, 0, sizeof(fdset));
        fdset[0].fd = STDIN_FILENO;
        fdset[0].events = POLLIN;

        ret = poll(fdset, nfds, timeout);

        if (ret < 0) {
            printf("\npoll() failed!\n");
            return -1;
        }

        if (fdset[0].revents & POLLIN) {
            // got a char from stdin
            ret = read(fdset[0].fd, &buf, 1);
            ui_in = buf[0];
            if ((ui_in == 'q') || (ui_in == 'Q')) {
                vs_end_play();
                //vs_quit();
                break;
            } else if ((ui_in == 'i')) {
                printf("# TAG ########################\n");
            } else if ((ui_in == 'h')) {
                printf("halting\n");
                vs_end_play_irq();
            } else if ((ui_in == 'p')) {
                vs_play_file(input_file);
            }
        }
        fflush(stdout);
    }
    vs_close();

    return ret;
}

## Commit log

2012-01-21 sch update
    [playa.brd, playa.sch]
2012-01-22 get closer to the datasheet
    [playa.brd, playa.sch]
2012-01-25 pcb completed
    [playa.brd, playa.sch]
2012-02-01 added TSOP31236 pkg and voltage sensing
    [playa.brd, playa.sch]
2012-02-04 latest pcb
    [playa.brd]
2012-02-05 sent to manufacture
    [playa.brd, playa.sch]
2012-02-14 use unconnected pin for random seed
2012-03-06 fixed vbat voltage sensing resistor values
    [playa.brd, playa.sch]
2012-03-18 detect battery voltage and stereo jack status
2012-03-18 modify battery voltage divider. it currently uses 35uA
    [playa.brd, playa.sch]
2012-06-29 verify accu charge, add sony rc decode values
2012-11-17 only allow 'power' IR sequence to wake up uC
2012-11-18 add power consumption profile
2013-05-25 add ir_remote driver
2013-05-26 adc is working
2013-05-27 rename traces to match the names given in the source code
    [playa.brd, playa.sch]
2019-03-08 switch to SPI1
2019-06-22 fix stream play canceling
    [spi.c, vs1063.c, vs1063.h]
2019-06-23 fix flac file closing with 0x800 SCI_MODE after cancel
    [vs1063.c]
